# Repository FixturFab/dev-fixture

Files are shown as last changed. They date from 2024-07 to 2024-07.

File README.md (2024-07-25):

# FixturFab Dev Test Fixture 

The Dev Test Fixture is an open source [bed-of-nails test fixture](https://en.wikipedia.org/wiki/Bed_of_nails_tester) to aid in firmware and manufacturing test development, and early stage manufacturing test. 

Dev

Dev Test Fixtures are available for sale on the [FixturFab Website](https://shop.fixturfab.com) in either a [Kit](https://shop.fixturfab.com/shop/210-0001-00-dev-test-fixture-kit-8764) or [Assembled](https://shop.fixturfab.com/shop/206-0016-00-dev-test-fixture-base-8431?category=3&search=dev) form. If you build or buy one, please help the project by documenting bugs with a GitHub issue. 

The Dev Test Fixture is designed to be a low-cost, easy to use fixture to help get someone started with low volume PCBA functional testing. Additional information on how to design and develop PCBA functional tests can be found at the [FixturFab Blog](https://fixturfab.com/articles/). 

## Dev Test Fixture Specifications

| Specification | Value |
|---|---|
| Max Board Size | 196mm x 180mm (7.7in x 7in) |
| Maximum Test Points | 100 |
| Service Life | 1K+ Units |
| Exchangeable Cartridge Support | No |
| Top Probing Support | No |  
| Side Probing Support | No |
| Weight | 1.4kg (3lbs) |
| Materials | Acrylic & MDF |

## Assembly and Release Files

Exported source (STLs, Assemblies, PDFs) can be found attached to the [latest release](google.com).

The latest working version of the Assembly can also be [viewed here](https://a360.co/3L6yBcP). 

## Compatible Probes, Receptacles, and Other Components

The Dev Test Fixture series is designed to utilize low-cost, readily available test probes and receptacles. Here is a list of recommended components: 

### Test Probes and Receptacles

Generic Probes and Receptacles with "2" (2.5mm) or "3" (5mm) collar heights are supported. Match the Probe and Receptacle pitches, (i.e P50 probes in R50 receptacles).

Receptacle part numbers take the following form: 

`R{pitch size}-{collar height}{termination style}`

Probe part numbers take the following form: 

`P{pitch size}-{tip style}{tip diameter}`

Pitch Sizes: 
- 100: 100mil/2.54mm minimum center to center spacing
- 75: 75mil/1.9mm minimum center to center spacing
- 50: 50mil/1.27mm minimum center to center spacing

Collar Heights: 
- 2: 2.5mm collar 
- 3: 5mm collat

Termination Styles:
- C: Crimp
- S: Solder Cup
- W: Wire Wrap

Tip Style: 
- A: Cup
- B: Needle
- LM: Spear
- Q: Waffle

Tip Diameter: 
- Varies widely, refer to the datasheet/documentation for the specific probe you are purchasing. 

These components can be sourced from sourced from Aliexpress, Amazon, or [FixturFab](https://shop.fixturfab.com). 

## Guide Pins

Locating the device under test can be done in many different ways, some methods are: 

- Spring Loaded Guide Pins
  - GP-2U - Umbrella Head
  - GP-2T - Threaded Head (M3 threads)
  - GP-2S - Spear Head
  - These components can be sourced from sourced from Aliexpress, Amazon, or [FixturFab](https://shop.fixturfab.com). 
- Dowel Pins 
  - Standard sizes can be found on Amazon or McMaster
- Cradle
  - Custom designed 3D printed or machine cradle
  - Attaches to the probe plate and aligns the DUT with the test probes

### Pressure Pins

Use a 45mm Pressure Pin (also referred to as POM). These can be 3D Printed, or sourced from Aliexpress, Amazon, or [FixturFab](https://shop.fixturfab.com).

## Contributing

If you would like to contribuute to the project, awesome! Check out the [contributing page]() to get started.

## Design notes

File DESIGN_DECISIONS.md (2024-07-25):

# Dev Test Fixture Design Decisions

This page aims to illustrate the design decisions behind the Dev Test Fixture. The design process started in early 2019 and has seen several iterations and improvements. This page gives background about why things are done the way they are, to help communicate with folks new to the project what has been tried, and why it was not chosen. 

## Overview

The Dev Test Fixture is a mostly laser-cut bed-of-nails test fixture. It features a hinged closing motion and a maximum working area of 196mm x 180mm. FixturFab rates the fixture to be capable of testing 1k+ units, and we have several customers have used it in production for >2k units successfully. 

## Changes

### Side Plates

Holes were added to the front/back plates to allow for optional side plates to be attached. This allows for the fixture to be completely enclosed, which is preferable when deploying to a fixture to the factory floor. 

### Pressure Plate Supports

The acrylic pressure plate would "bow" significantly in high probe count (>50) test fixtures. To counteract this bow, 3D printed Pressure Plate Supports can be added. The default pressure plate has the mounting holes for these supports, which can be added at any time to the fixture if needed. 

### Pressure Plate (Lid) Locks

The pressure plate would consistently close due to no mechanism in place to keep it open. 3D printed lid locks are added to the hinge mounting screws which can be used to keep the pressure plate open when the fixture is not in use. 

### 2 and 3 Collar Height Support 

The generic Rxxx-2x and Rxxx-3x receptacles have differing heights. To support both of these receptacles, different back plate heights are provided. Use the corresponding back plate height for the receptacle size that is used within the fixture. 

### Tall Fixture Plates

A "Tall" variant was designed to provide additional space within the test fixture base for instrumentation, wiring, etc. To use this version, replace the Front and Back Plates with the "Tall" versions

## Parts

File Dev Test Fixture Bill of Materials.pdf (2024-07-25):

# BoM Overview

# [210-0001-00] Dev Test Fixture Kit

Product | Quantity | Lead Time | Route
[210-0001-00] Dev Test Fixture Kit | 1.00 Unit | 0 Days Manufacture: [210-0001-00] Dev Test Fixture Kit
[101-0001-03] Dev Fixture Kit | 1.00 Unit | 0 Days Manufacture: [101-0001-03] Dev Fixture Kit
[301-0007-00] Fastener, M3x8mm, Button Head | 8.00 Unit | 2 Days Buy: McMaster-Carr
[204-0007-00] Pressure Pin, 50mm Long, 3mm Tip | 2.00 Unit | 21 Days Buy: zoy
[301-0002-00] Fastener, 4-40x3/8", Button Head | 18.00 Unit | 2 Days Buy: McMaster-Carr
[301-0005-00] Fastener, M3x10mm, Button Head | 4.00 Unit | 7 Days Buy: JLCMC
[300-0003-00] Mounting Bracket, 4-40, RA | 9.00 Unit | 1 Days Buy: Digikey
[306-0001-00] Clamp, 4001 | 1.00 Unit | 2 Days Buy: Amazon - Vendor
[305-0004-00] Insert, M4, 6.35mm D, 4.7mm L | 2.00 Unit | 1 Days Buy: McMaster-Carr
[301-0003-00] Fastener, M4x8mm, Button Head | 4.00 Unit | 2 Days Buy: McMaster-Carr
[801-0001-00] Acrylic, Black, Gloss, 1/4" Thick, 12" x 20" Sheet | 1.00 Unit | 5 Days Buy: ePlastics

[305-0002-00] Insert, M3, 4.2mm D, 6mm L | 4.00 Unit | 1 Days Buy: McMaster-Carr
[301-0006-00] Fastener, M3x6mm, Button Head | 4.00 Unit | 2 Days Buy: McMaster-Carr
[300-0004-00] Hinge, 18mmx175mm, Silver | 1.00 Unit | 21 Days Buy: kimxin
[105-0098-00] DEV260 Lock - Right | 1.00 Unit | 0 Days Manufacture: [105-0098-00] DEV260 Lock - Right
[802-0005-00] Filament, Matte PLA, Army Blue | 1.63 g | 2 Days Buy: Amazon - Vendor
[105-0099-00] DEV260 Lock - Left | 1.00 Unit | 0 Days Manufacture: [105-0099-00] DEV260 Lock - Left
[802-0005-00] Filament, Matte PLA, Army Blue | 3.04 g | 2 Days Buy: Amazon - Vendor
Operations | 00:30 minutes
3D Print - DEV260 Pro Latch - Fabrication | 00:30 minutes
Byproducts | 1.00
[105-0098-00] DEV260 Lock - Right | 1.00 Unit
[801-0004-00] MDF, 1/4" Thick, 10" x 20" Sheet | 0.50 Unit | 5 Days Buy: Glowforge
[801-0002-00] Acrylic, Clear, Gloss, 1/4" Thick, 12" x 20" Sheet | 0.50 Unit | 5 Days Buy: ePlastics
Operations | 60:00 minutes
LASER - [210-0001-00] Dev Fixture DIY Kit - FF-SEA-LASER-01 | 60:00 minutes
Product | Quantity | Lead Time | Route

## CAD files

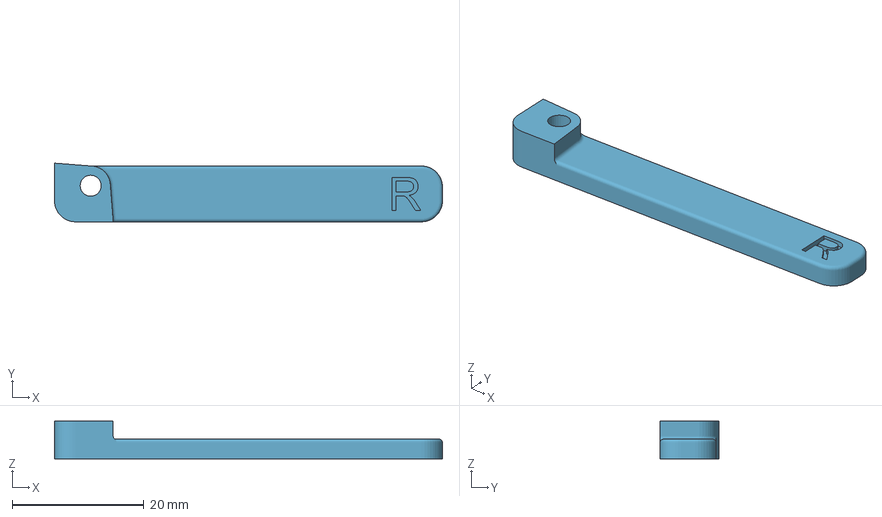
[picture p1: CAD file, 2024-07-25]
stl/105-0098-00 - Dev, Lid Lock - Right.3mf
59.0 x 8.93 x 5.75 mm

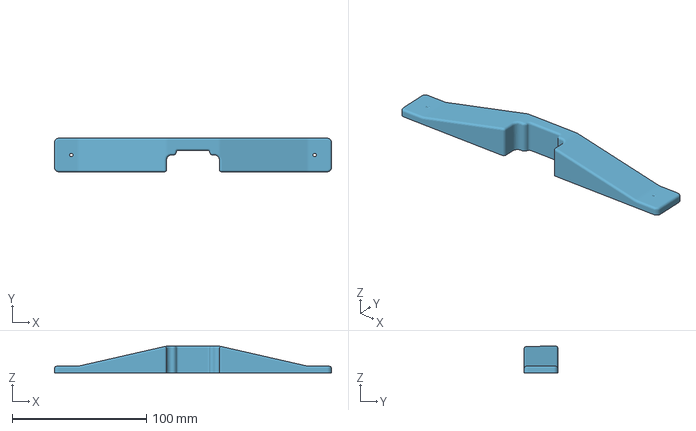
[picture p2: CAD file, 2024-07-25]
stl/105-0106-00 - Pressure Plate Support Front.3mf
206.0 x 25.0 x 20.0 mm

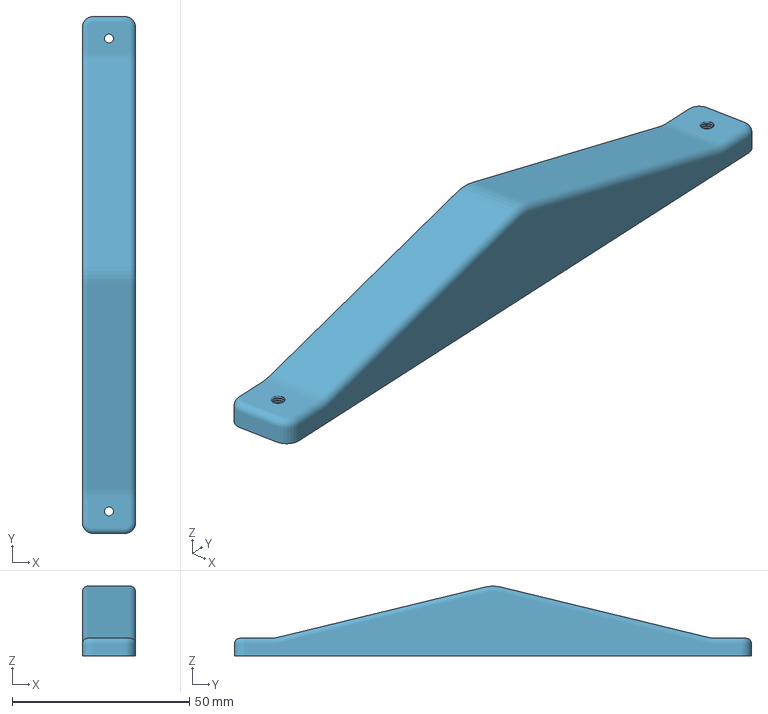
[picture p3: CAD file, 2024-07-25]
stl/105-0107-00 - Pressure Plate Support Side.3mf
15.0 x 146.0 x 19.7 mm

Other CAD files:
stl/105-0099-00 - Dev, Lid Lock - Left.3mf
